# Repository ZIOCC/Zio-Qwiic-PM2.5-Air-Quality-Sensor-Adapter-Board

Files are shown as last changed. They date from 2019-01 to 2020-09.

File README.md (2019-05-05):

# Zio Qwiic PM2.5 Air Quality Sensor Adapter Board

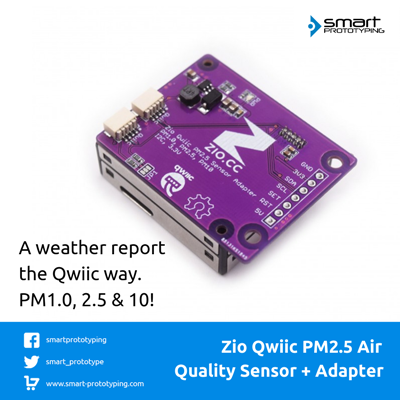
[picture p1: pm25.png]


> This product can be available for purchase [here](https://www.smart-prototyping.com/Zio-Qwiic-PM-Air-Quality-Sensor-and-Adapter-Board).

#### Description

This is a PM sensor + Qwiic adapter board product, you will get the PM sensor and an easy to use adapter board.

The PM sensor is a compact (compare to the other PM sensors) and accurate sensor. It can directly output the PM 1.0, 2.5, 10.0 rate of the air in unit of the µg/m3 (PM standard unit), just like the weather report.

This is an I2C version of the sensor, which also has UART interface version.  The adapter board can be directly attached to the sensor with the female header, and we offer you two ways to setup the connection, the easiest way is to use Qwiic cable to connect to Qwiic connector, with no soldering; another way is soldering the breakout pins. 

The adapter board can be fixed very well by the 2.0mm screws with the two 2.0mm holes on the board. And there are two 3mm mounting holes for you to fix this module to any other place you want.

Note 1: the fan on the sensor needs 5v to drive it. We have added a voltage step-up circuit to convert the I2C 3.3V (Qwiic connector) to 5V for the fan. So please be sure to use 5V power when you are using these breakout pins.

Note 2: The sensor needs to take around 30s to warm up to get the accurate data.

#### Specification

* IC: PMSA003I
* I2C address: 0x12
* Operation Current: less than 100mA
* Operation Temperature: -10 to 60 degrees Celsius.
* Adapter board dimension: 44.3 x 35.0mm
* PM sensor Dimension: 12.2 x 35.3 x 38.3 mm
* Total Weight: 24.8g

#### Links

* [PCB Source file](https://github.com/ZIOCC/Zio-Qwiic-PM2.5-Air-Quality-Sensor-Adapter-Board/tree/master/EAGLE)
* [PCB schematic](https://github.com/ZIOCC/Zio-Qwiic-PM2.5-Air-Quality-Sensor-Adapter-Board/blob/master/zio%20qwiic%20pm%20sensor%20adapter%20board.pdf)
* [Demo code](https://github.com/ZIOCC/Zio-Qwiic-PM2.5-Air-Quality-Sensor-Adapter-Board/tree/master/PMSA003I)
* [PM sensor PMSA003I Datasheet](https://github.com/ZIOCC/Zio-Qwiic-PM2.5-Air-Quality-Sensor-Adapter-Board/blob/master/PMSA003%20series%20data%20manua_English_V2.6.pdf) (Not very good English in the datasheet, [contact us](mailto:info@smart-prototyping.com) if you have any question)

###### About Zio
> Zio is a new line of open sourced, compact, and grid layout boards, fully integrated for Arduino and Qwiic ecosystem. Designed ideally for wearables, robotics, small-space limitations or other on the go projects. Check out other awesome Zio products [here](https://www.smart-prototyping.com/Zio).

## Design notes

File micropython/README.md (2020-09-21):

This is a demo code for the micropython board work with a PM sensor and display the PM value on the 1.5inch OLED display. If you don't want to use the display, just remove the display code.

PMSA003I PM sensor: https://www.smart-prototyping.com/Zio-Qwiic-PM-Air-Quality-Sensor-and-Adapter-Board

1.5inch OLED Display: https://www.smart-prototyping.com/Zio-Qwiic-OLED-Display-1_5inch-128x128

Micropython board: https://www.smart-prototyping.com/Zio-Micropython-PYBoard-V1_1

Connections: Use the Qwiic cable daisy chain them together.

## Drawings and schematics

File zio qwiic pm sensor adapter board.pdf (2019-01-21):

+3V3 | 4.7uF ±10% ¹⁰V | 100nF ±10% ⁵⁰V
1 | 2 | 3 | 4

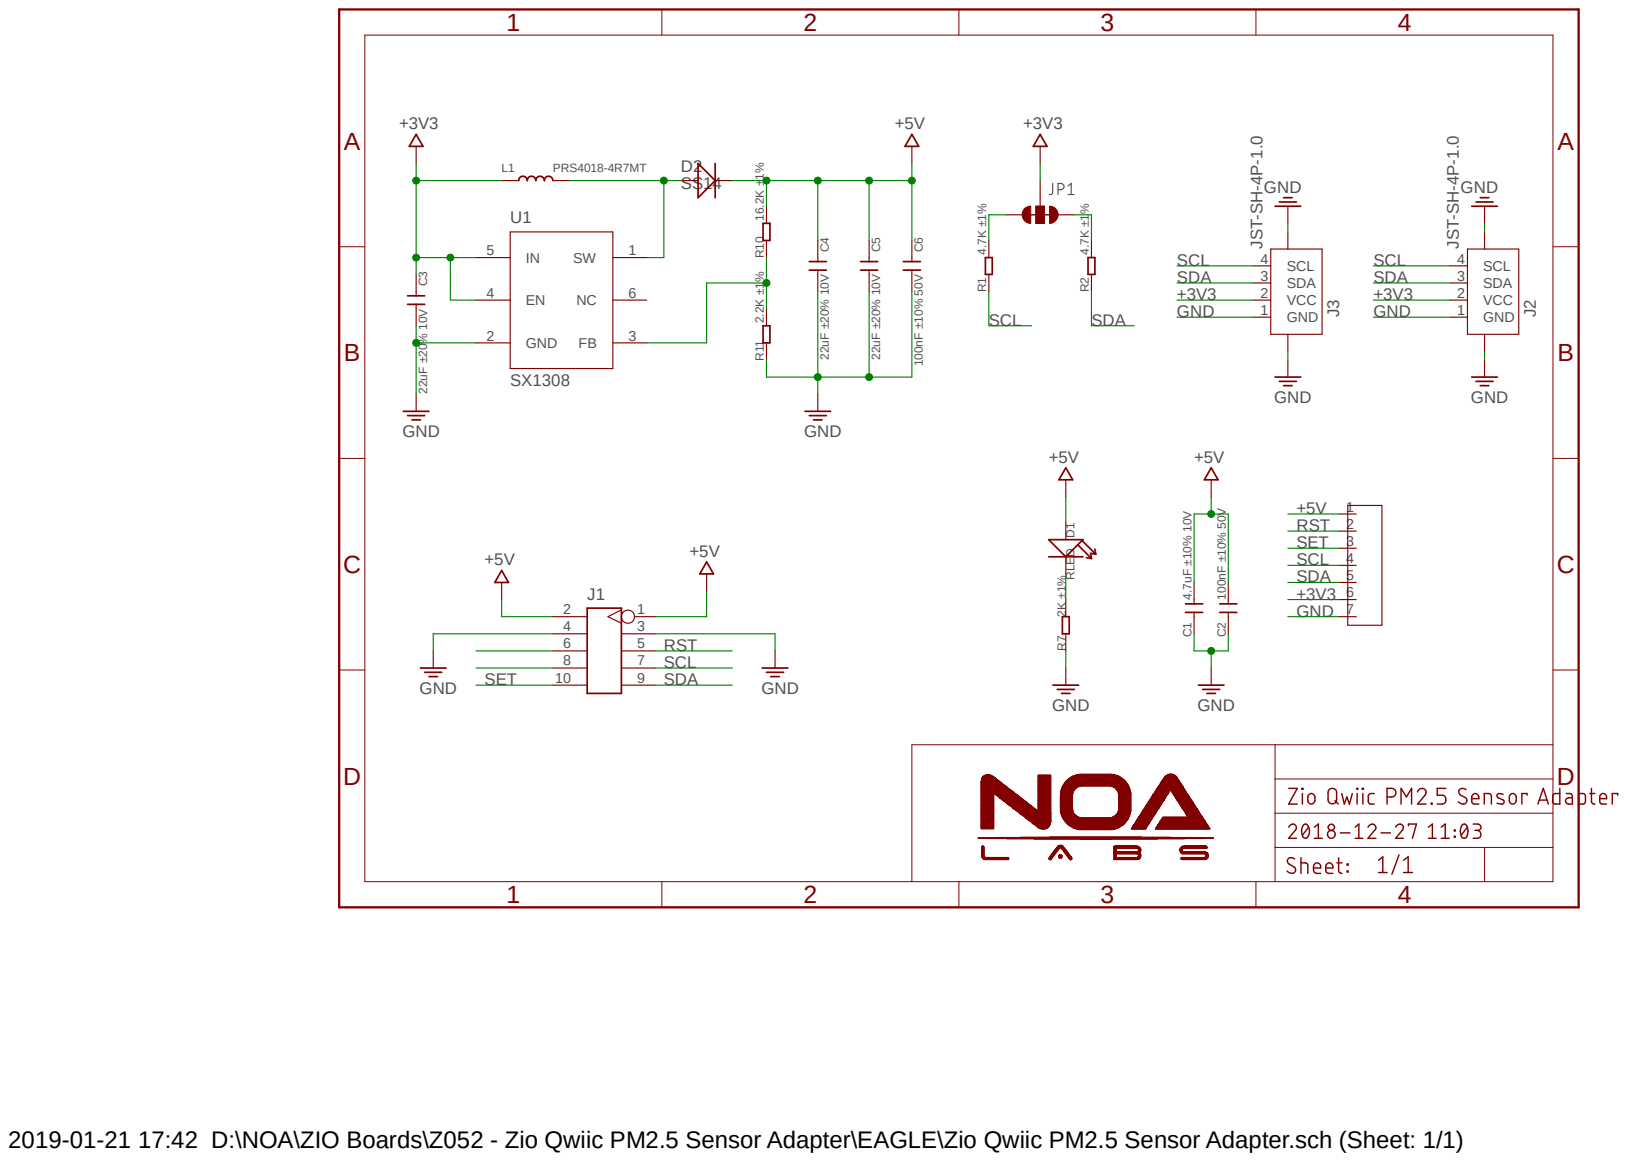
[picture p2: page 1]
GND; GND 4.7K ±1%; RLED 2K ±1%; PRS4018-4R7MT; SS14 22uF ±20% ¹⁰V; 22uF ±20% ¹⁰V ¹⁶.2K ±1% 2.2K ±1%; 100nF ±10% ⁵⁰V; +5V 22uF ±20% ¹⁰V; GND 1; VCC 2; SDA 3; SCL 4; J2 JST⁻SH⁻⁴P⁻¹.0; J3 JST⁻SH⁻⁴P⁻¹.0 R¹; GND 2; C⁴ R¹⁰ R¹¹; RST; SCL; SDA; SET

2019-01-21 17:42 D:\NOA\ZIO Boards\Z052 - Zio Qwiic PM2.5 Sensor Adapter\EAGLE\Zio Qwiic PM2.5 Sensor Adapter.sch (Sheet: 1/1)

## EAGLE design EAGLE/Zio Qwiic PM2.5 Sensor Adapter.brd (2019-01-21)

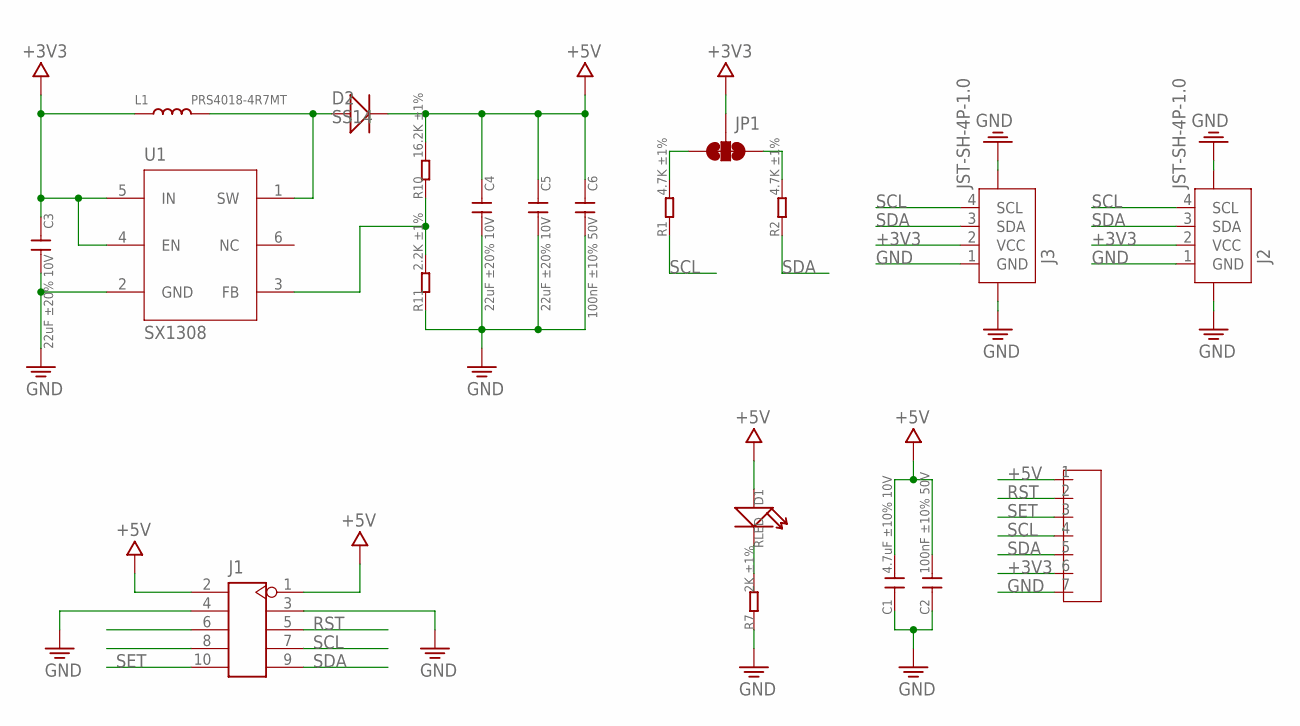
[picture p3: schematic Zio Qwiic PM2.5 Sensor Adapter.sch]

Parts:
C1: 4.7uF ±10% 10V; C0603
C2, C6: 100nF ±10% 50V; C0603
C3, C4, C5: 22uF ±20% 10V; C0805
D1: RLED; LED-0603
D2: SS14; DO-214AC
J1: HEADER-2X5P-PM2.5; 2X5P-1.27-THT-PM2.5
J2, J3: JST-SH-4P-1.0; JST-SH-4P
J5: HEADER-7P; 7P-2.54-60/35MIL
JP1: SMT-JUMPER_3_2-NC_TRACE
L1: PRS4018-4R7MT; L4030
R1, R2: 4.7K ±1%; R0603
R7: 2K ±1%; 0603
R10: 16.2K ±1%; R0603
R11: 2.2K ±1%; R0603
U1: SX1308; SOT23-6

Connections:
+3V3: C3.1, J2.2 (VCC), J3.2 (VCC), J5.6, JP1.2, L1.1, U1.4 (EN), U1.5 (IN)
+5V: C1.2, C2.2, C4.1, C5.1, C6.1, D1.+, D2.C (-), J1.1, J1.2, J5.1, R10.2
GND: C1.1, C2.1, C3.2, C4.2, C5.2, C6.2, J1.3, J1.4, J2.1 (GND), J2.NC1 (5), J2.NC2 (6), J3.1 (GND), J3.NC1 (5), J3.NC2 (6), J5.7, R7.1, R11.1, U1.2 (GND)
unnamed: JP1.1, R2.2
unnamed: D1.-, R7.2
unnamed: JP1.3, R1.2
unnamed: R10.1, R11.2, U1.3 (FB)
NC1: J1.6
NC2: J1.8
RST: J1.5, J5.2
SCL: J1.7, J2.4 (SCL), J3.4 (SCL), J5.4, R1.1
SDA: J1.9, J2.3 (SDA), J3.3 (SDA), J5.5, R2.1
SET: J1.10, J5.3
SW: D2.A (+), L1.2, U1.1 (SW)

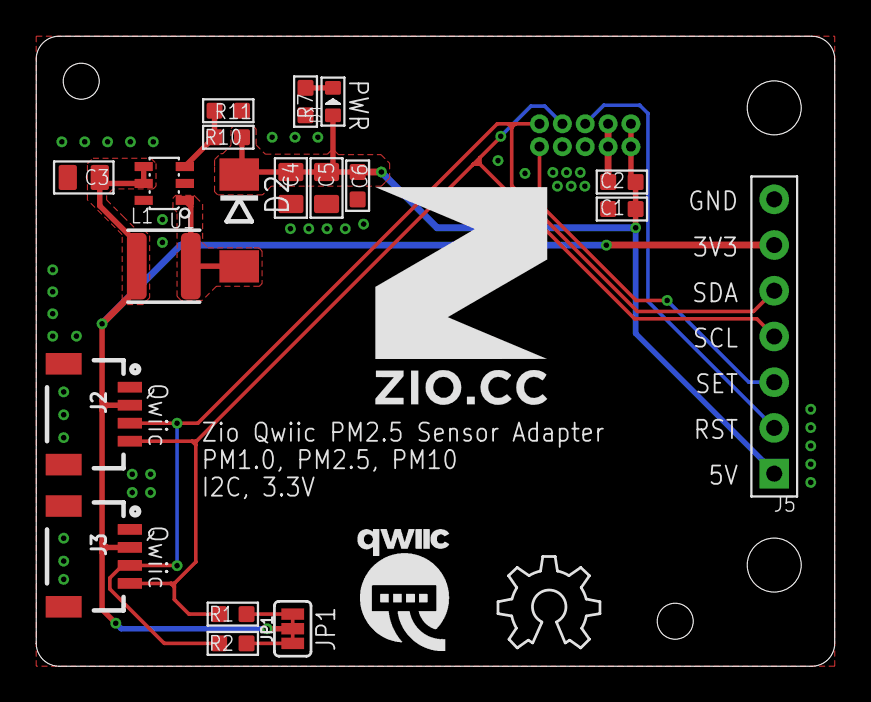
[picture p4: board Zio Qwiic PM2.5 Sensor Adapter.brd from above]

Board: 2 copper layers, 44.4 x 35.0 mm, 23 parts (1 on the bottom side), 12 nets.

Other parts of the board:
U$6: QWIIC-LOGO-MEDIUM
U$7: OSHW_6X200_NOTEXT
U$9: 12MM

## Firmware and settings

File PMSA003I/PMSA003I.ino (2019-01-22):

// Wire Master Reader
// by Nicholas Zambetti <http://www.zambetti.com>

// Demonstrates use of the Wire library
// Reads data from an I2C/TWI slave device
// Refer to the "Wire Slave Sender" example for use with this

// Created 29 March 2006

// This example code is in the public domain.


#include <Wire.h>

#define address 0x12
#define HEADER_H  0x42
#define HEADER_L  0x4D
#define FRAME_LENGTH  0x1C

uint8_t COMMAND = 0x00;
uint8_t Sensor_Databufer[32];

unsigned char cur_rx_data;
unsigned char pre_rx_data;
unsigned char main_status=0;
unsigned char recv_buff[256]={0};
unsigned char recv_buff_index=0;
unsigned char incomingByte;

int pm1_0_cf_1=0;
int pm2_5_cf_1=0;
int pm10_cf_1=0;

int pm1_0=0;
int pm2_5=0;
int pm10=0;

unsigned short check_sum;

void setup() {
  Wire.begin();        // join i2c bus (address optional for master)
  Serial.begin(9600);  // start serial for output
  pinMode(13,OUTPUT);
}

void loop() {
  digitalWrite(13,HIGH);
  Wire.requestFrom(address, 32);
  while(Wire.available())
  {
    cur_rx_data = Wire.read();
    switch(main_status)
     {
      case 0:
         if( cur_rx_data == HEADER_L )
         {
            if( pre_rx_data ==  HEADER_H )
            {
                 main_status++;
                 
                 check_sum += pre_rx_data;
                 check_sum += cur_rx_data;
                 
                 cur_rx_data = 0;
                 pre_rx_data = 0;

                 
            }
         }else
         {
            pre_rx_data = cur_rx_data;
         }
        break;
        case 1:
        if( cur_rx_data == FRAME_LENGTH )
         {
            if( pre_rx_data ==  0x00 )
            {
                 main_status++;
                 
                 check_sum += pre_rx_data;
                 check_sum += cur_rx_data;
                 
                 cur_rx_data = 0;
                 pre_rx_data = 0;
            }
         }else
         {
            pre_rx_data = cur_rx_data;
         }
        break;
        case 2:
        recv_buff[recv_buff_index++] = cur_rx_data;
        check_sum += cur_rx_data;
        if( recv_buff_index == 26)
        {
             main_status++;
          
             cur_rx_data = 0;
             pre_rx_data = 0;
        }
        break;
        case 3:
        recv_buff[recv_buff_index++] = cur_rx_data;
        if( recv_buff_index == 28)
        { 
            if( check_sum == ( (recv_buff[26]<<8) + recv_buff[27]) )
            {
                recv_buff_index = 0;  
                pm1_0_cf_1 = (recv_buff[recv_buff_index] << 8) + recv_buff[recv_buff_index+1];
                recv_buff_index += 2;
                pm2_5_cf_1 = (recv_buff[recv_buff_index] << 8) + recv_buff[recv_buff_index+1];
                recv_buff_index += 2;
                pm10_cf_1 = (recv_buff[recv_buff_index] << 8) + recv_buff[recv_buff_index+1];
                recv_buff_index += 2;
                
                pm1_0 = (recv_buff[recv_buff_index] << 8) + recv_buff[recv_buff_index+1];
                recv_buff_index += 2;
                pm2_5 = (recv_buff[recv_buff_index] << 8) + recv_buff[recv_buff_index+1];
                recv_buff_index += 2;
                pm10 = (recv_buff[recv_buff_index] << 8) + recv_buff[recv_buff_index+1];
                
                Serial.print("PMSA003I:    ");
//                Serial.print("pm1.0_cf_1:");Serial.print(pm1_0_cf_1,DEC);Serial.print("ug/m3");Serial.print("  ");
//                Serial.print("pm2.5_cf_1:"); Serial.print(pm2_5_cf_1,DEC);Serial.print("ug/m3");Serial.print("  ");
//                Serial.print("pm10_cf_1:");Serial.print(pm10_cf_1,DEC);Serial.print("ug/m3");Serial.print("  ");
                Serial.print("pm1.0:  ");Serial.print(pm1_0,DEC);Serial.print("ug/m3");Serial.print("  ");
                Serial.print("pm2.5:  ");Serial.print(pm2_5,DEC);Serial.print("ug/m3");Serial.print("  ");
                Serial.print("pm10:  ");Serial.print(pm10,DEC);Serial.println("ug/m3");
            }
            main_status = 0;    
            cur_rx_data = 0;
            pre_rx_data = 0; 
            check_sum = 0;
            for(int i=0;i< 256; i++)
            {
              recv_buff[i] = 0x00;
            }
            recv_buff_index = 0x00;      
        }
        break;
        case 4:
        break;
        case 5:
        break;
        case 6:
        break;
        case 7:
        break;
        case 8:
        break;
        case 9:
        break;
        case 10:
        break;
        case 11:
        break;
         case 12:
        break;
        case 13:
        break;
     } 
    }
//  Read_Sensordata();
  delay(500);
  digitalWrite(13,LOW);
  delay(500);
}


void Read_Sensordata()
{
  uint8_t i=0;
  Wire.requestFrom(address, 32);
  while (Wire.available()) { // slave may send less than requested
    Sensor_Databufer[i++] = Wire.read(); // receive a byte as character
            
  }
  Serial.println("Sensor_Data:  ");
  for(i=0;i<32;i++)
  {
    Serial.print(i);
    Serial.print(":  ");
    Serial.println(Sensor_Databufer[i],HEX); 
    }
  }

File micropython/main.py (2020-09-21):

from machine import Pin,I2C
import pmsa003i
import ssd1327

i2c = I2C(sda=Pin("Y10"), scl=Pin("Y9"),freq=10000)

pmsensor = pmsa003i.PMSA003I(i2c, 0x12)
display = ssd1327.QWIIC_128X128_OLED(i2c)

while True:
    pmsensor.read()
    display.fill(0)
    display.text('PM 2.5 cf: ' + str(pmsensor.pm2_5_cf),0,10,15)
    display.text('PM 10.0: ' + str(pmsensor.pm10_0),0,30,15)
    display.text('pm2.5 per 0.1L: ',0,50,15)
    display.text(str(pmsensor.pm2_5_qty), 0, 62, 15)
    display.show()
    pyb.delay(1000)
